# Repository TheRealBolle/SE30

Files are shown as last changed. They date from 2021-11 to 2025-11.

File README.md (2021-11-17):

# Macintosh SE/30 Logicboard recreation
  
This is a recreation of the Macintosh SE/30 logicboard.  
It is not a 1:1 copy of the original logicboard but instead the original schematics were used to completely redesign and route a lookalike board.  
  
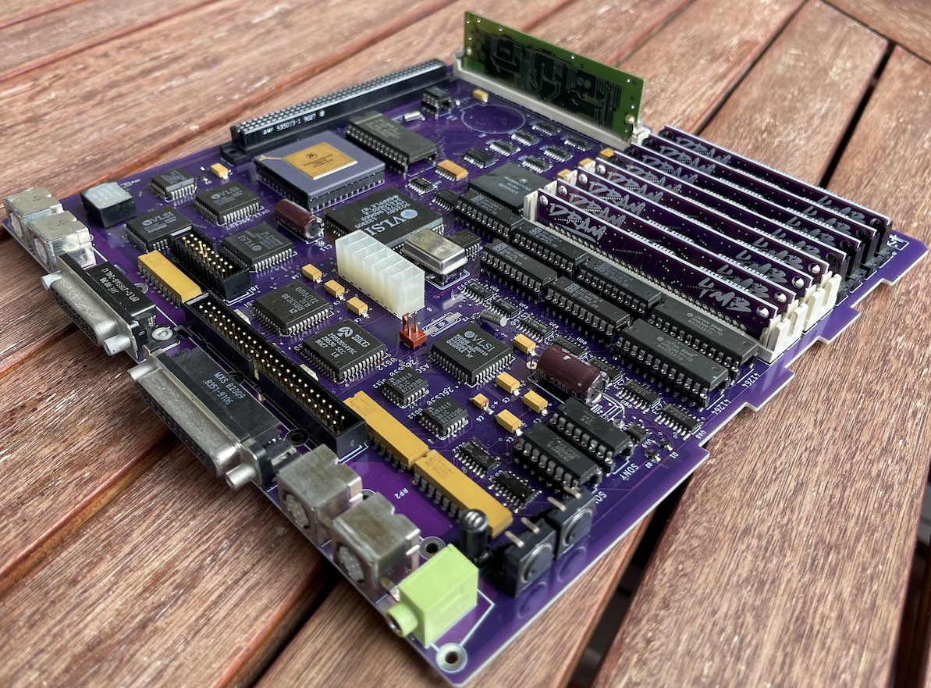
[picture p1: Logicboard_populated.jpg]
fully populated board

  
The provided logicboard files are licensed under CC-BY-NC-SA - they are NOT intended for commercial use.  

# Reverse engineered PALs
  
The original PALs have been reverse-engineered and equations were rewritten to match the behaviour of the originals - the provided
JEDEC files are not dumps of the content of the original chips.

The provided JEDEC files are intended to be used with a 16V8-type device (GAL16V8, PALCE16V8, ATF16V8) as a replacement
for the video, clock and RAM-signalling PALs. Certain low power ATF16V8B don't work. ATF16V8C use pinkeepers instead of internal pullups and might be problematic as well.  
  
Board locations and original part number reference:  
  
UI6 341-0665-A  
UH7 341S0689-C  
UG6 341-0747-A  
UG7 341-0746-A  
UE6 341-0754-A  
UE7 341-0755-A  

# Board Files
  
The provided gerber files have been generated using the JLCPCB EAGLE cam job files.  
Pick and place data is intended to be used with JLCPCB as well.  
Other manufacturers might have different requirements to the gerbers.  

# BOM
  
A BOM is available at:  
https://docs.google.com/spreadsheets/d/1CAzGjHxQaQrduQC-hQ8sB2I6Y56fUlCWdJMCUDho0NE

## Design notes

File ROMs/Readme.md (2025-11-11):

These files are a stock SE/30 ROM split up into four files and bitswapped to be used with the onboard PLCC32 FlashROM (F010 or F040) sockets.
When using the PLCC sockets make sure to bridge the two solder switches on the bottom of the board at the marked (V) position.
If a ROM SIMM is used the two ROM jumpers can be left open.

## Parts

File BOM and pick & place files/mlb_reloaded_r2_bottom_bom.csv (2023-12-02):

Comment | Designator | Footprint | LCSC Part #
10 | R14 R15 | R1206 | C17903
22 | R16 R17 R18 R19 R23 R25 R26 R29 R30 | R1206 | C17958
27 | R10 R11 R33 | R1206 | C17946
47 | R3 R4 R21 R22 R28 | R1206 | C25384
75 | R24 | R1206 | C17987
100 | R5 | R1206 | C17901
150 | R9 | R1206 | C17917
180 | R12 R13 | R1206 | C17924
470 | R31 | R1206 | C25383
1k | R1 R2 R34 | R1206 | C4410
1.2k | R20 | R1206 | C17891
3.3k | R8 | R1206 | C26032
4.7k | R27 R32 | R1206 | C17936
330k | R6 R7 | R1206 | C17929
10pF | C45 | C1206 | C1883
33pF | C33 C34 C44 C67 C73 | C1206 | C1906
68pF | C40 | C1206 | C106002
2.2nF | C17 | C1206 | C77511
10nF | C20 C28 C30 C31 C38 C47 C48 C49 C51 C52 C57 C58 C59 C62 C64 C65 C68 C72 C81 C83 C84 | C1206 | C153292
100nF | C16 C18 C19 C21 C22 C23 C24 C25 C26 C27 C29 C32 C35 C36 C37 C39 C41 C42 C43 C46 C50 C53 C54 C55 C56 C60 C61 C63 C66 C69 C70 C71 C74 C75 C76 C77 | C1206 | C24497
BAS40-06 | D4 D5 D6 D7 D8 D9 D10 D11 D12 D13 D14 D15 D16 D17 D18 D19 | SOT23 | C406043
100Ω@100MH | L8 L9 L10 L11 L12 L13 L14 L15 L16 L17 L18 L19 L20 L21 L22 | 1806 | C525678

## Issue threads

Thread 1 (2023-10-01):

Eagle files?

jameswood, 2023-10-01:
Hello,

This is so fantastic! I have an SE/30 with a questionable motherboard and am strongly considering reloading it.

I’d love to attempt to convert it for 72-pin RAM… for no good reason, really!

Have you shared (or would you consider sharing) your working Eagle files?

(Apologies if you’ve answered this question before: I’ve searched everywhere I can think of and haven’t seen it asked or answered.)

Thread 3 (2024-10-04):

Feature Mention in "This Does Not Compute" - Retro Mac Build Using Your Project

dariuszsikorski, 2024-10-04:
Hi there,

I wanted to let you know that a video titled "I built a retro Mac from BRAND NEW parts!" was recently published on the This Does Not Compute YouTube channel: [Watch it here](https://www.youtube.com/watch?v=zc3sPoqOFG8)

The video showcases your project in action! The creator rebuilt a retro Mac using the design you developed for the motherboard. I couldn't find any contact info or email to reach you directly, so I thought I'd drop this as a GitHub issue in case you're interested. Of course, feel free to close it or do whatever you see fit – maybe even mention it in the README as a cool project highlight.

There's also a brief mention of a minor error with one of the trace connections at 14:02 in the video. It might be worth looking into and updating the motherboard schematic.

Overall, this is a very exciting project, and I’m thrilled to see your work getting such attention. Kudos to the creator for taking the time to recreate the motherboard based on your work!

Best regards!

reinauer, 2025-02-11:
Is this present on all versions prior to R4? Is there documentation on the rework other than the video?

Closed 2024-11-21.

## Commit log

2021-11-13 Create gerbers go here
2021-11-13 Create bom goes here
2021-11-13 Update and rename bom goes here to BOM on google docs
2021-11-13 Update BOM on google docs
2022-01-30 Create boards
2022-03-03 Create boards files will be right back...
2022-11-04 Create board
2022-11-28 Update mlb_reloaded_r2_bottom_bom.csv
    added inductors... JLC part C525678 should do the job and come closest to what has been measured:
    https://68kmla.org/bb/index.php?threads/macintosh-se-30-logicboard-recreation-thread-revival.39485/post-449820
    C85842 should work as well.
    [mlb_reloaded_r2_bottom_bom.csv]
2025-11-29 Use JLC basic part C1846 for 10nF capacitors
2025-11-29 Fix orientation of diodes
